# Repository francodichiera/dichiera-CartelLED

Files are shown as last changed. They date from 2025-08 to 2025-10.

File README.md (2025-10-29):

# Cartel LED inteligente Proyecto Final 2025
###
<p align="center">
  Imagen 1
</p>

<table align="center">
  <tr>
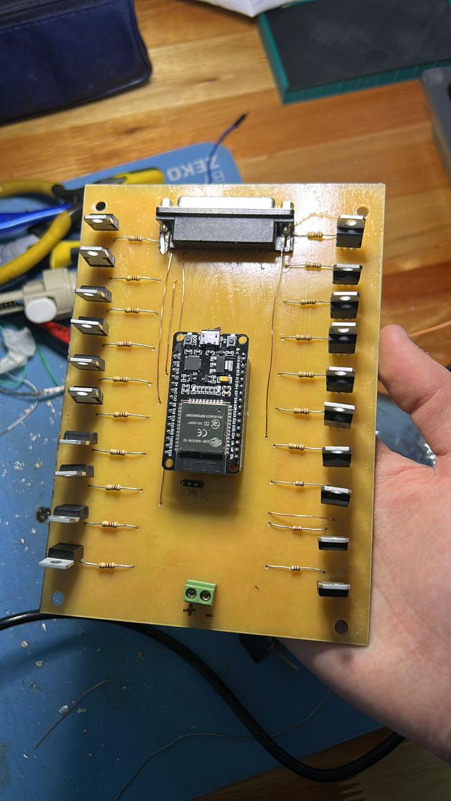
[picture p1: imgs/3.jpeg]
Imagen 3
    <td></td>
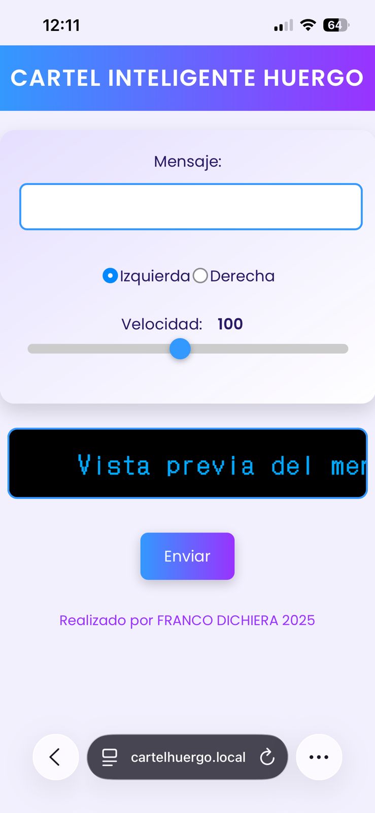
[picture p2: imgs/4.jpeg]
Imagen 4
    <td></td>
  </tr>
</table>

###
## 
- Proyecto: cartel LED multiplexado controlado por ESP32, columnas por 3×74HC595 (24 cols), filas por transistores TIP122.
(POR CADA MODULO).

- EL CARTEL CUENTA CON 18 FILAS x 96 COLUMNAS (4 MODULOS CONECTADOS HORIZONTALMENTE).

- CON UNAS DIMENSIONES DE LA ESTRUCTURA DE: 1.7m x 40cm.

## Agradecimientos

Antes de pasar a la explicacion, quiero agradecer especialmente al **Prof. Ing. Facundo Luzko** por su importante ayuda y guía en la programación del cartel, al **Prof. Ricardo Malvasio** por su valiosa orientación y colaboración durante el desarrollo del proyecto, y a **mi viejo**, por su apoyo incondicional en todo momento.

# Resumen

Este repositorio contiene el firmware para un cartel LED multiplexado con ESP32. Usa 3 registros 74HC595 en cascada para controlar 24 columnas y 18 pines del ESP32 (a través de transistores TIP122 o drivers) para seleccionar filas. El microcontrolador corre un servidor web simple que permite enviar el texto que se desplaza horizontalmente (scroll), elegir dirección y velocidad y persiste la configuración en flash con `Preferences`.

# Características

-   Matriz: `MATRIX_ROWS = 18`, `MATRIX_COLS = 24` (configurable).
    
-   Control de columnas por 3×`74HC595` en cascada.
    
-   Control de filas por pines del ESP32 (transistores TIP122 u otro driver).
    
-   Framebuffer en RAM: `framebuffer[MATRIX_ROWS][BYTES_PER_ROW]`.
    
-   Librería gráfica `Adafruit_GFX` + fuente compilada.
    
-   Interfaz web responsive para editar el mensaje, ver demo y ajustar velocidad/dirección.
    
-   Persistencia con `Preferences` (mensaje, velocidad, dirección).
    
-   mDNS disponible: `cartelhuergo.local` (si mDNS funciona en tu red).

----------

# Diagrama y conexionado (detalle)

> **Nota importante:** el ejemplo asume columnas manejadas por 74HC595 como _fuente_ (HIGH = +V para anodos) y filas controladas por NPN (TIP122) que _conectan a GND_ (sink) cuando activadas. Esta es la configuración que coincide con el comportamiento del código (`sr.set(b, HIGH)` y `digitalWrite(filas[f], HIGH)` para activar fila).

### Conexiones básicas

Señales principales (ESP32 ↔ 74HC595)

- DATA_PIN (23) -> Serial Data (DS / SER) del primer 74HC595

- CLOCK_PIN (18) -> Shift clock (SH_CP)

- LATCH_PIN (19) -> Store clock / latch (ST_CP)

### Salidas 74HC595 -> columnas

-   Q0..Q7 (primer registro) -> columnas 0..7
    
-   Q0..Q7 (segundo registro) -> columnas 8..15
    
-   Q0..Q7 (tercer registro) -> columnas 16..23

Asegurate del orden físico: la librería / código usa `sr.set(b, value)` con `b` de 0 a 23. Si tus registros están conectados en distinto orden, reordena o ajusta mapping.

### Filas (por TIP122)

Cada fila física (catodo común en el esquema) va a un TIP122 que tiene:

-   Colector -> pin fila (panel LED)
    
-   Emisor -> GND
    
-   Base -> pin ESP32 a través de resistencia de 1k  
    En el código `digitalWrite(filas[f], HIGH)` activa la fila (enciende transistor, conecta a GND).

### Alimentación

-   **Fuente**: calcula la corriente por LED (Iled) × cantidad máxima encendida simultáneamente. En multiplexado de filas, una sola fila se enciende a la vez, por lo que la corriente máxima es (#LEDsPorFila × Iled). Ejemplo: 24 LEDs por fila × 20 mA = 480 mA por fila (añadir margen). Para 18 filas multiplexadas no sumes todas; la fuente debe poder suministrar el pico por fila y la electrónica.
    
-   **Voltage registers**: 74HC595 soporta Vcc 2–6V; si usas LED de 5V considera 5V lógica o usar nivel shifters. Con ESP32 (3.3V) se suele usar 5V para LEDs y la salida del 74HC595 a 5V está OK si los 74HC595 toleran 3.3V en entradas. Revisa datasheets o usa versiones 74HCT (más compatible con 3.3V).
    
-   GND común obligatorio.

----------

# Cómo funciona (conceptos clave)

1.  **Framebuffer**: `uint8_t framebuffer[MATRIX_ROWS][BYTES_PER_ROW];`
    
    -   Cada fila tiene `BYTES_PER_ROW` bytes (3) → 24 columnas → 24 bits por fila.
        
    -   El bit más significativo (0x80) corresponde a la columna `x % 8 == 0` por el cálculo `0x80 >> (x % 8)`.
        
2.  **Dibujo**: Heredas `Adafruit_GFX` con `MatrixDisplay` y sobreescribes `drawPixel(x,y,color)`. Cuando se escribe texto con `display.print(curMessage)` Adafruit_GFX setea pixels en el framebuffer.
    
3.  **Multiplexado**:
    
    -   `refrescarMatrizCompleta()` recorre filas `f = 0..MATRIX_ROWS-1`.
        
    -   Para cada fila: apaga fila previa, envía todos los 24 bits (columnas) al `74HC595` con `sr.set(b, ...)`, activa la fila actual (`prenderFila(f)`), espera `delayMicroseconds(100)` y la apaga.
        
    -   Los LEDs que deben estar on durante esa fila se encienden porque sus columnas están `HIGH` (desde el 74HC595) y la fila está siendo _sink_ por el TIP122.
        
4.  **Scroll**:
    
    -   `xPos` controla la posición horizontal; cada `scrollSpeed` ms el texto avanza `±1`.
        
    -   `display.getTextBounds()` calcula anchura `w` del texto para resetear `xPos`.
        
5.  **Web**:
    
    -   Un web server simple en puerto 80 sirve `WebPage` y procesa parámetros en URL `?MSG=...&SD=L|R&SP=xxx`.
        
    -   El código parsea URL en `getData()` decodificando `%xx`.
        
6.  **Persistencia**:
    
    -   `Preferences` guarda `mensaje`, `speed`, `dir` para restaurar tras reset.

----------

## Explicación técnica: ¿qué es y cómo funciona un TIP122?

**TIP122 — resumen práctico**

-   El TIP122 es un transistor Darlington NPN empaquetado (dos transistores en cascada dentro de un solo encapsulado).
    
-   Ventaja: **ganancia de corriente muy alta** (β muy grande), por eso con poca corriente de base podés conmutar corrientes relativamente altas en el colector.
    
-   Desventaja: **alta caída de saturación** (VCE(sat) típicamente ~1.5–2.5 V dependiendo de corriente), lo que produce **pérdida de potencia** y calor. Además la caída base-emisor de la entrada es mayor (~2.5–3V total, por las dos uniones).

**Cómo se usa en el cartel**

-   Usamos TIP122 como _sink_ por fila: cuando su base recibe HIGH, el transistor conecta la fila a GND permitiendo que los LEDs de esa fila con columna HIGH se iluminen.
    
-   Colocá **una resistencia en la base** entre ESP32 y la base del TIP122 (ej. 1kΩ es una buena práctica). Esto limita la corriente desde el pin del ESP32.

**Cálculos y precauciones**

-   Si `I_collector = 480 mA` y `VCEsat ≈ 2 V` → potencia en el transistor `P = VCEsat × I = 2 V × 0.48 A = 0.96 W`. Esto **genera calor** y normalmente requiere disipador.
    
-   Con ESP32 (GPIO a 3.3 V) la base del TIP122 queda con poca tensión sobre la resistencia (Vbase ≈ 2.5 V), por eso la corriente de base es pequeña — aun así la ganancia Darlington suele permitir conmutar la corriente del colector.
    
-   **Recomendación:** para menor pérdida térmica y menor VCE(sat) usar un **MOSFET N-channel lógico (logic-level)** como alternativa — mucho menor VDS(on) y menos calor. Ej: si conseguís un MOSFET de canal N con Rds(on) bajo y que se active con 3.3 V (IRLZ44N no siempre es la mejor opción, buscá específicamente “logic-level MOSFET”), vas a reducir pérdidas térmicas.

**Valores orientativos**

-   Resistencia base típica: `1kΩ` (puede ajustarse entre 470Ω y 4.7kΩ según diseño).
    
-   Verifica disipación térmica y agrega disipador o cambialo por MOSFET si vas a manejar corrientes grandes.

----------

## Explicación técnica: ¿qué es y cómo funciona un 74HC595?

**74HC595 — resumen práctico**

-   Es un _registro de desplazamiento (shift register)_ con latch y 8 salidas paralelas (Q0..Q7).
    
-   Funcionalmente tiene dos registros internos:
    
    -   **Shift register**: donde se van desplazando los bits con cada pulso de reloj (SH_CP).
        
    -   **Storage register** (o latch register): se actualiza cuando se pulsea ST_CP (latch). De este modo podés enviar muchos bits sin que las salidas cambien hasta que hagas latch.
        
-   Señales principales:
    
    -   `SER` (DS): serial data in
        
    -   `SH_CP` (clock): desplaza un bit en el shift register al flanco activo
        
    -   `ST_CP` (latch): copia el contenido del shift register al storage register → las salidas cambian
        
    -   `Q0..Q7`: salidas paralelas
        
    -   `Q7'` (o Q7S/Q7') suele ser serial out para encadenar el siguiente 74HC595 (cascada)
        
    -   `OE` (Output Enable, activa low) y `MR` (Master Reset, activa low) controlan si las salidas están habilitadas o si el registro se resetea

**Por qué lo usamos**

-   Permite controlar **muchas columnas** con solo 3 pines del micro (data, clock, latch).
    
-   Con `Q7'` encadenás los registros y podés manejar 24 columnas en serie.

**Consejos de uso**

-   **Cargar todos los bits** (ej. 3 bytes) en el shift register con pulsos de clock y al final hacer un `latch` para actualizar las salidas en una operación atómica. Esto evita glitches.
    
-   `OE` lo podés usar para blanking rápido (si querés apagar todas las salidas momentáneamente).
    
-   `MR` te permite resetear las salidas (activo bajo).

**Limitaciones eléctricas importantes**

-   Los pines del 74HC595 no están pensados para conducir corrientes muy altas de forma sostenida. Aunque pueden entregar decenas de mA en condiciones cortas, **no es buena idea esperar 20–25 mA sostenidos por salida sin verificar la hoja de datos**.
    
-   En multiplexado, cada salida del 74HC595 típicamente solo alimenta un LED a la vez (por fila), lo que reduce la corriente sostenida por pin, pero **es crucial usar resistencias por LED** y mantener la corriente por pin dentro de límites razonables.
    
-   Para compatibilidad con **ESP32 (3.3 V)** se recomienda la versión **74HCT595** o comprobar que la lógica 74HC595 que uses interpreta 3.3 V como HIGH de forma fiable. `74HCT` suele aceptar 3.3 V como HIGH cuando la alimentación del chip es 5 V — aún así, revisar datasheets.

**Buenas prácticas**

-   Si necesitás más corriente o brillo, usar drivers especializados para LEDs (p. ej. registros con driver de corriente constante) o agregar transistores por columna si vas a exigir >10 mA por salida.
    
-   Si microcontrolador y 74HC595 comparten diferentes tensiones (3.3V vs 5V), considera conversión de niveles o usar 74HCT compatibles.

# Dependencias y preparación del entorno

-   **Placa:** ESP32 (seleccionar en Arduino IDE -> Board Manager).
    
-   **Librerías (instalar desde Library Manager / Git):**
    
    -   `ShiftRegister74HC595` (o la que uses; tu código ya referencia la plantilla `ShiftRegister74HC595<3>`).
        
    -   `Adafruit_GFX` (para la API gráfica).
        
    -   `ESPmDNS` (incluida con núcleo ESP32).
        
    -   `Preferences` (incluida).
        
    -   Fuente convertida a header: `LEMONMILK_Regular11pt7b` (como `Fonts/LEMONMILK_Regular11pt7b.h`). Para convertir TTF → Adafruit font: usar `truetype2gfx` o `fontconvert` (links en comentarios del código).
        
        > `https://rop.nl/truetype2gfx/ FONTS PAGE`

### Recomendaciones de configuración en Arduino IDE

-   Board: `ESP32 Dev Module` (o el modelo exacto)
    
-   Flash Frequency: 80 MHz
    
-   Upload Speed: 115200 o 921600 (según tu puerto)
    
-   Partition Scheme: default (si necesitas mucha NVS, ajustar)

----------

# Interfaz Web / API

-   Página principal (sirve `WebPage`) incluye demo y formulario.
    
-   **Enviar**: pulsa `Enviar` en la UI → hace `window.location='/?MSG='+msg+'&SD='+SD+'&SP='+SP`.
    
-   **Formato URL manual**:
    
    `http://<IP_DEL_ESP32>/?MSG=Tu%20mensaje%20aqui&SD=L&SP=100` 
    
    -   `MSG` = texto codificado en URL (máx 255 chars en tu buffer).
        
    -   `SD` = `L` (izquierda) o `R` (derecha).
        
    -   `SP` = velocidad (entero). En tu código `scrollSpeed` en ms.
        
-   **Demo**: la demo en el HTML hace scroll CSS/JS y usa fuente tipo LED (DotGothic16).

----------

# Configuraciones persistentes

-   Namespace `prefs.begin("cartel", false);`
    
-   Keys:
    
    -   `"mensaje"` (String)
        
    -   `"speed"` (uint)
        
    -   `"dir"` (bool)
        
-   Para resetear preferencias manualmente: puedes añadir un endpoint `/reset` que haga `prefs.clear()` o borrar desde código.

----------

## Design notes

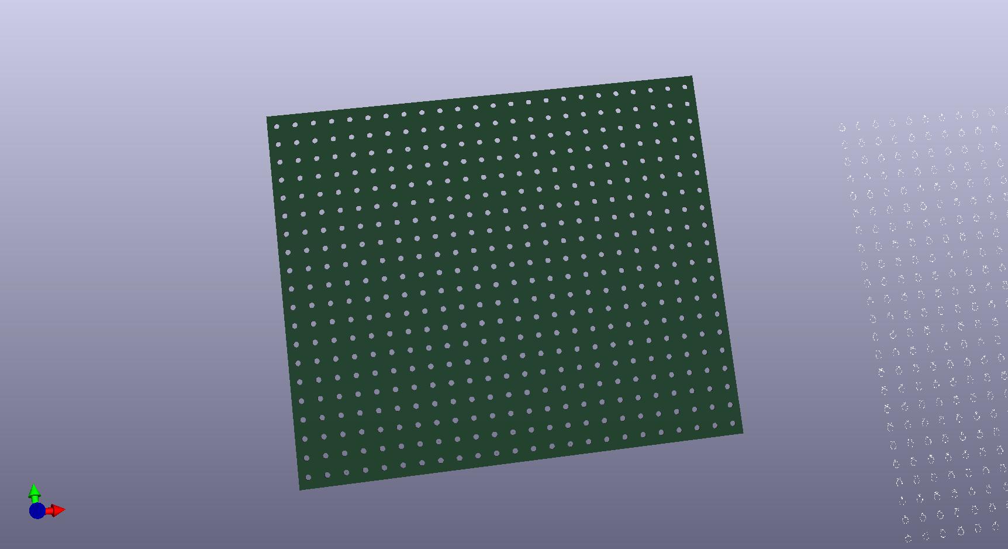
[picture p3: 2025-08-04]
assets/Matriz Franco 20x24/cartelmatriz.jpg

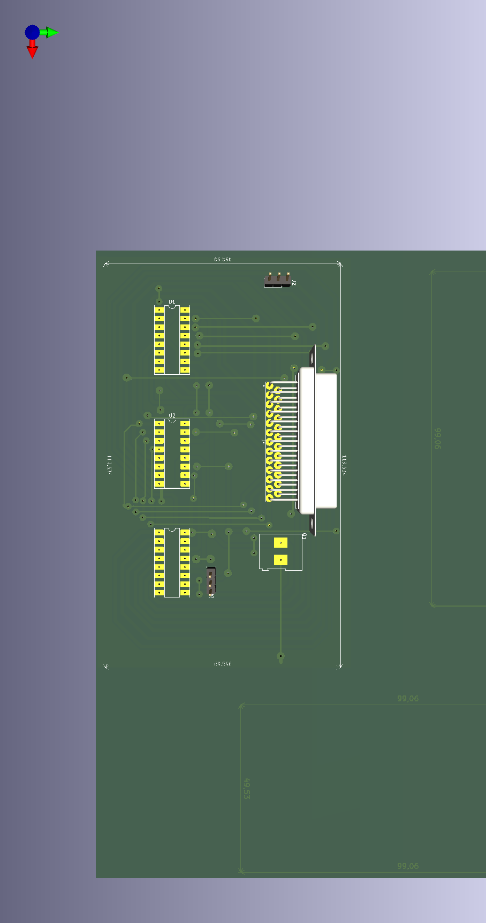
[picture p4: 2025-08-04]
assets/Placa 74hc595 Version 2/74hc595/74hc595.png

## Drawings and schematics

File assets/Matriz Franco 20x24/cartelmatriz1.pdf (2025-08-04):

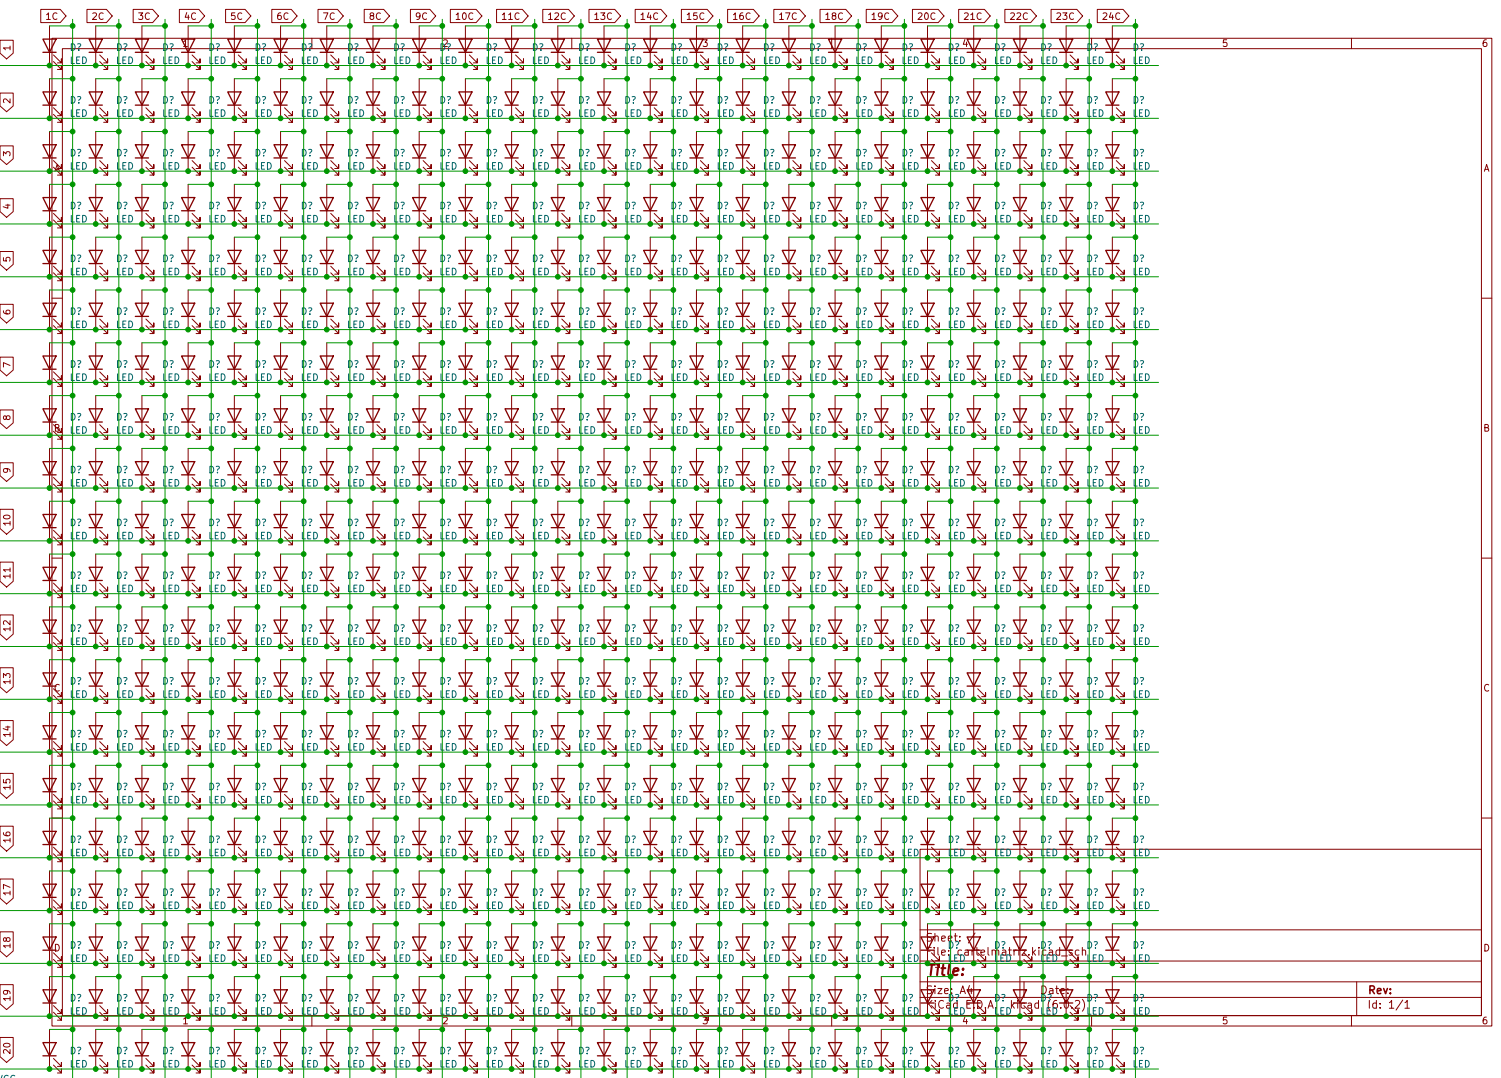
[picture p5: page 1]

D? | D? | D? | D?
LED | LED | LED | LED | LED

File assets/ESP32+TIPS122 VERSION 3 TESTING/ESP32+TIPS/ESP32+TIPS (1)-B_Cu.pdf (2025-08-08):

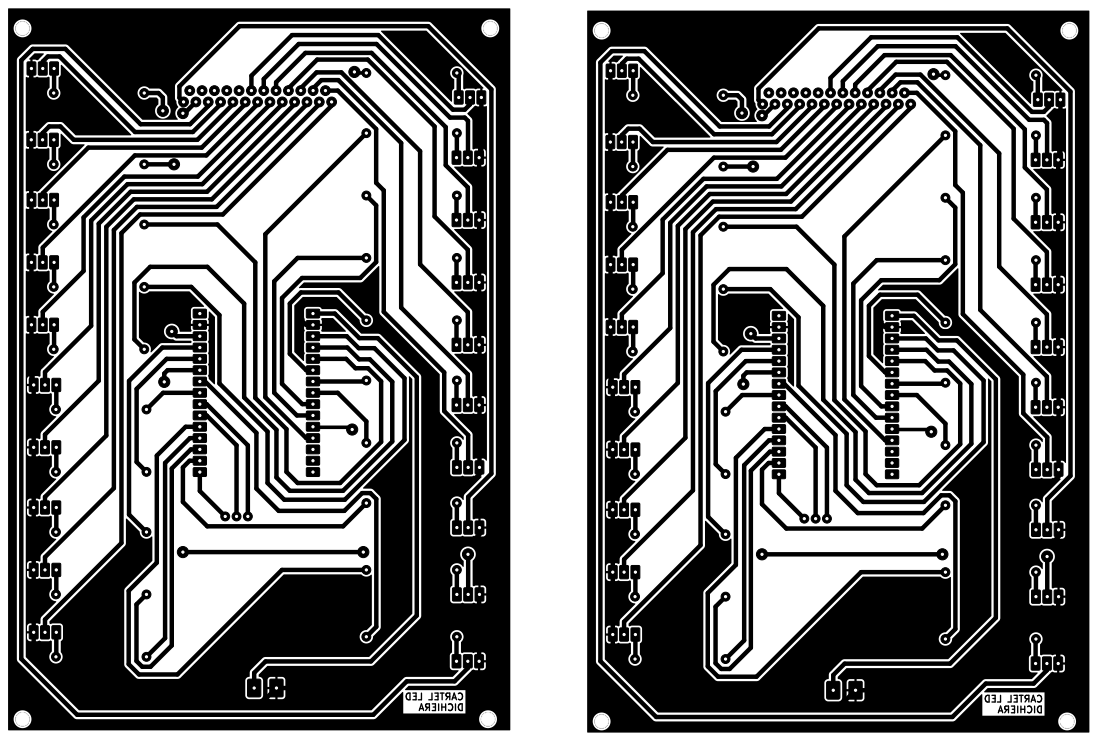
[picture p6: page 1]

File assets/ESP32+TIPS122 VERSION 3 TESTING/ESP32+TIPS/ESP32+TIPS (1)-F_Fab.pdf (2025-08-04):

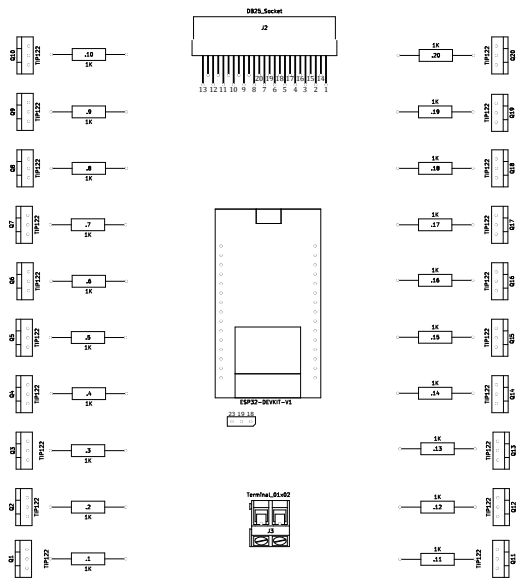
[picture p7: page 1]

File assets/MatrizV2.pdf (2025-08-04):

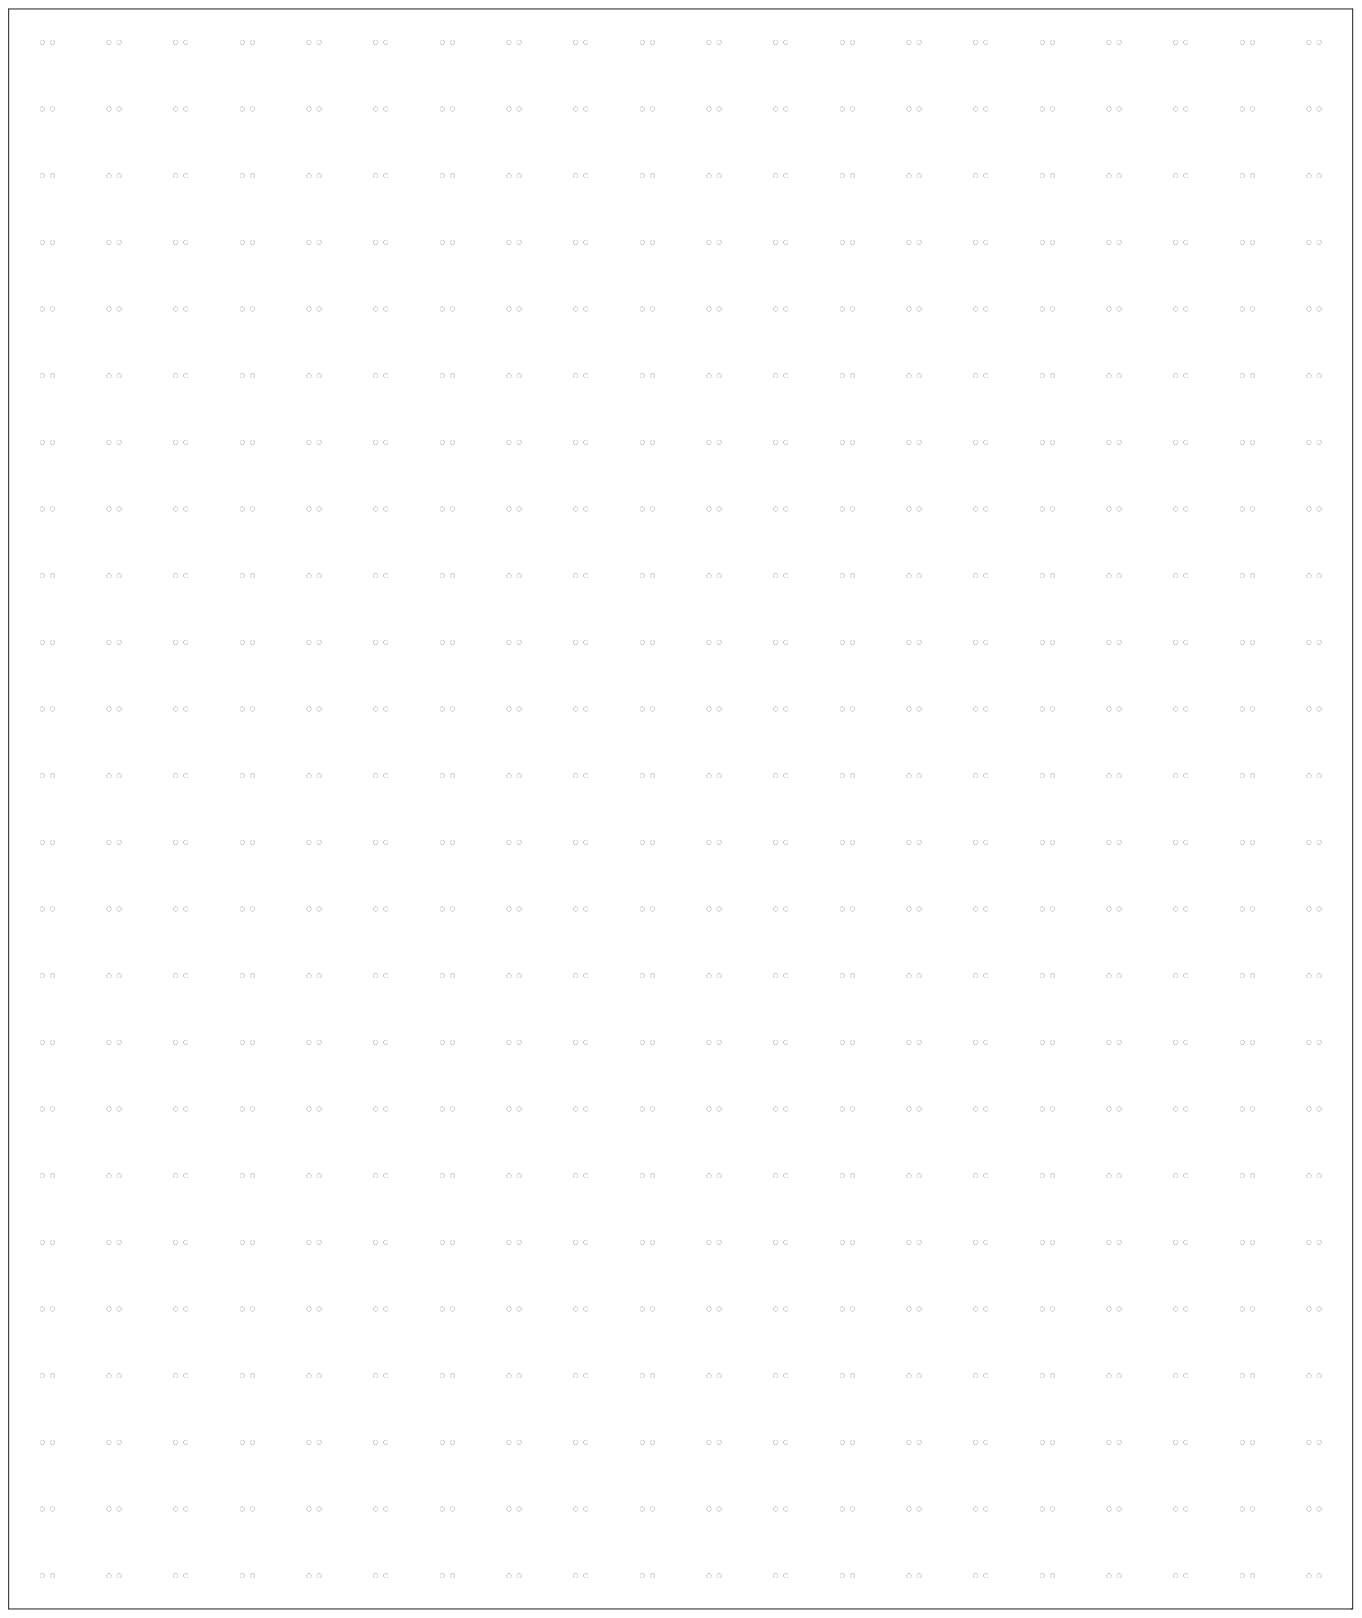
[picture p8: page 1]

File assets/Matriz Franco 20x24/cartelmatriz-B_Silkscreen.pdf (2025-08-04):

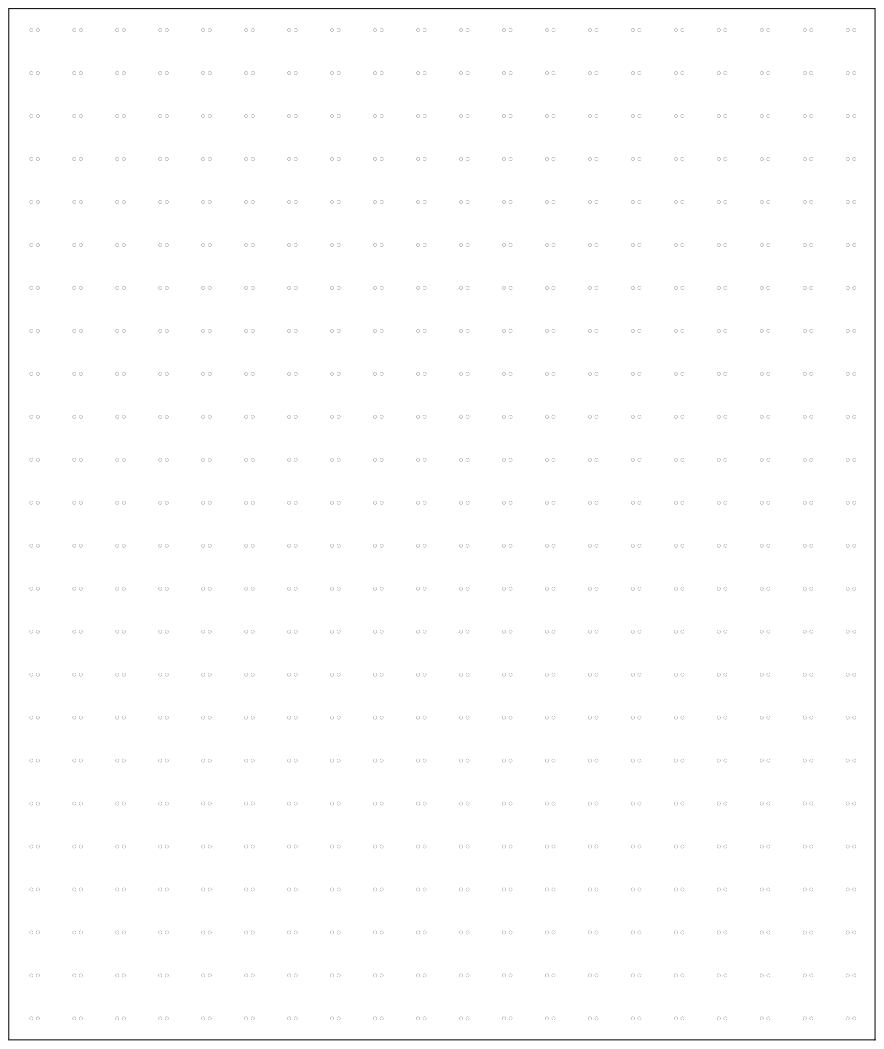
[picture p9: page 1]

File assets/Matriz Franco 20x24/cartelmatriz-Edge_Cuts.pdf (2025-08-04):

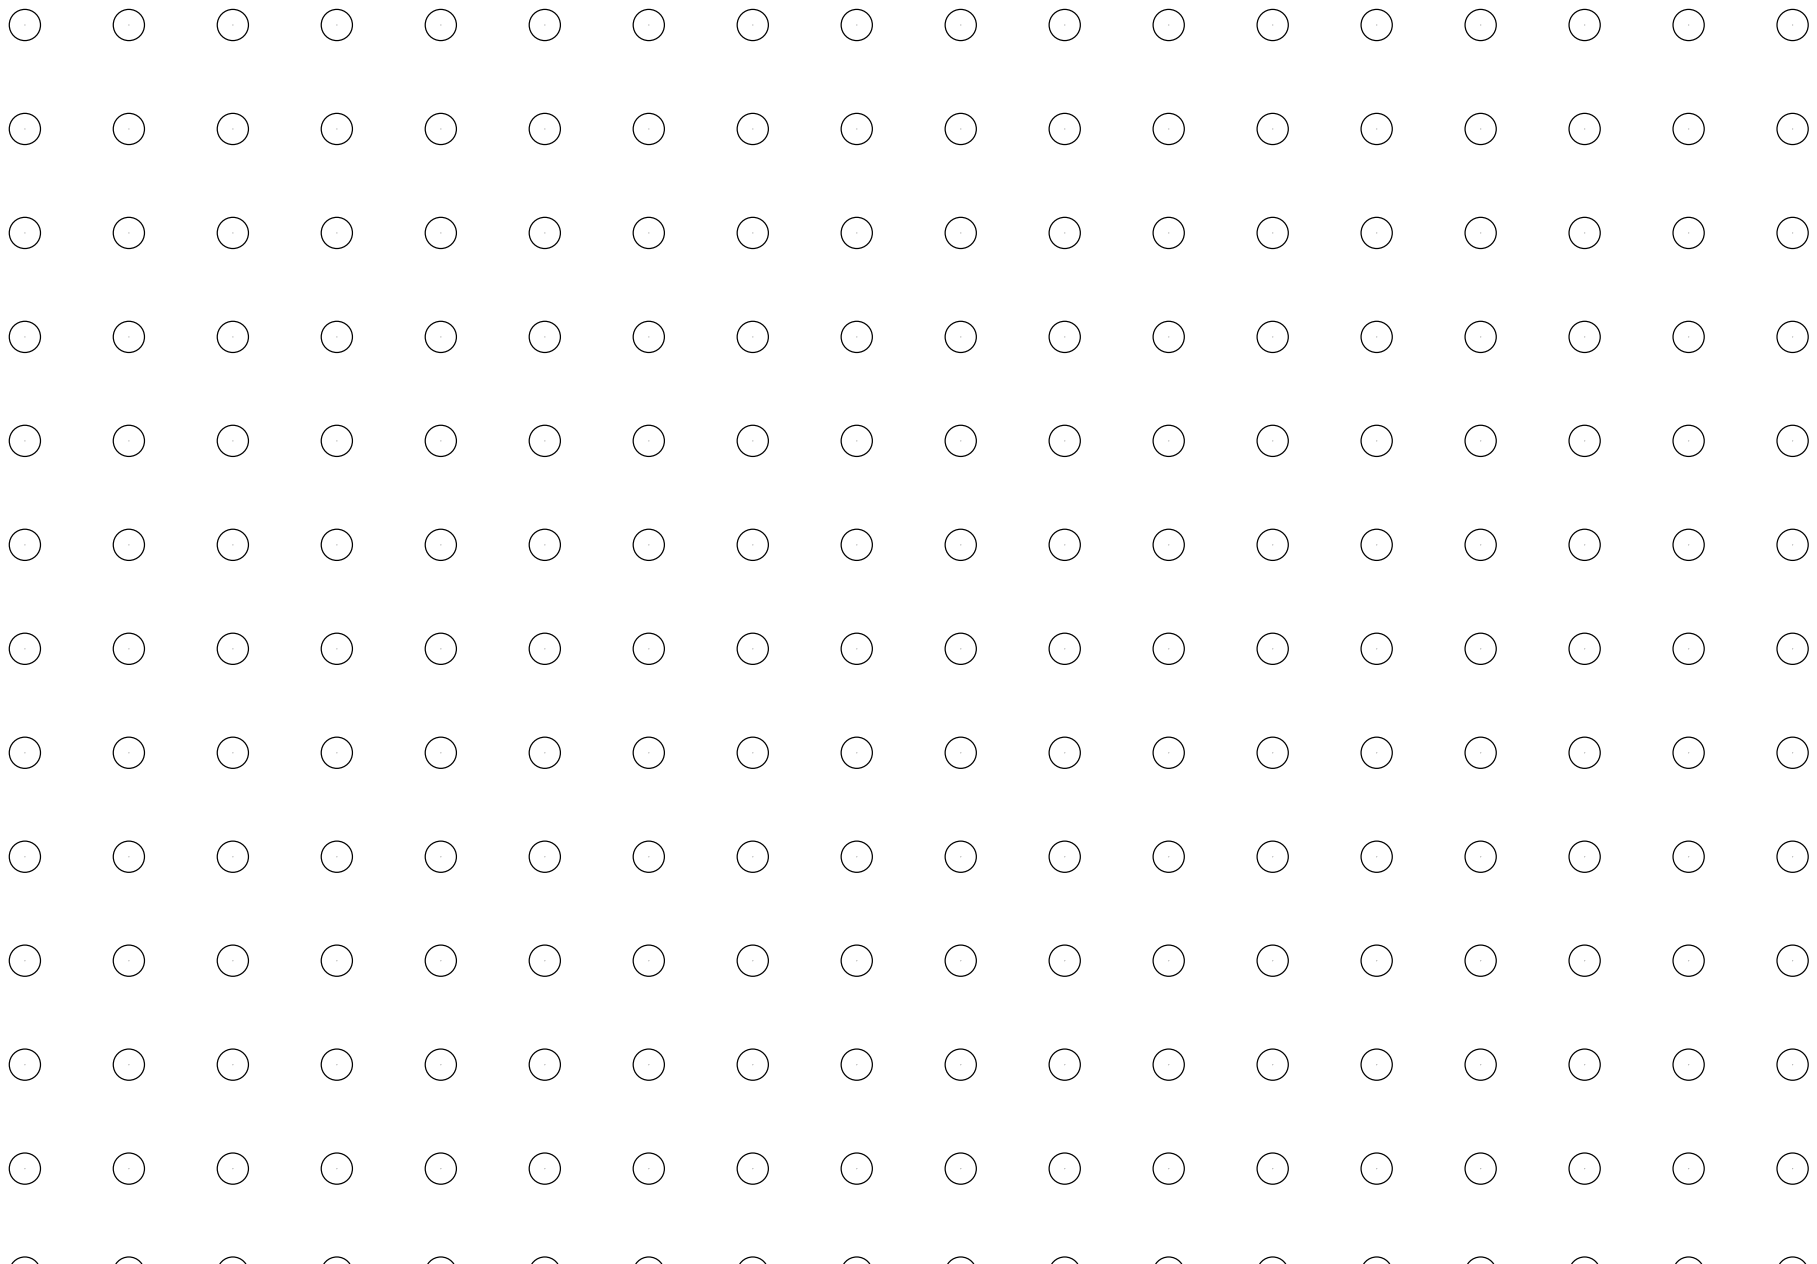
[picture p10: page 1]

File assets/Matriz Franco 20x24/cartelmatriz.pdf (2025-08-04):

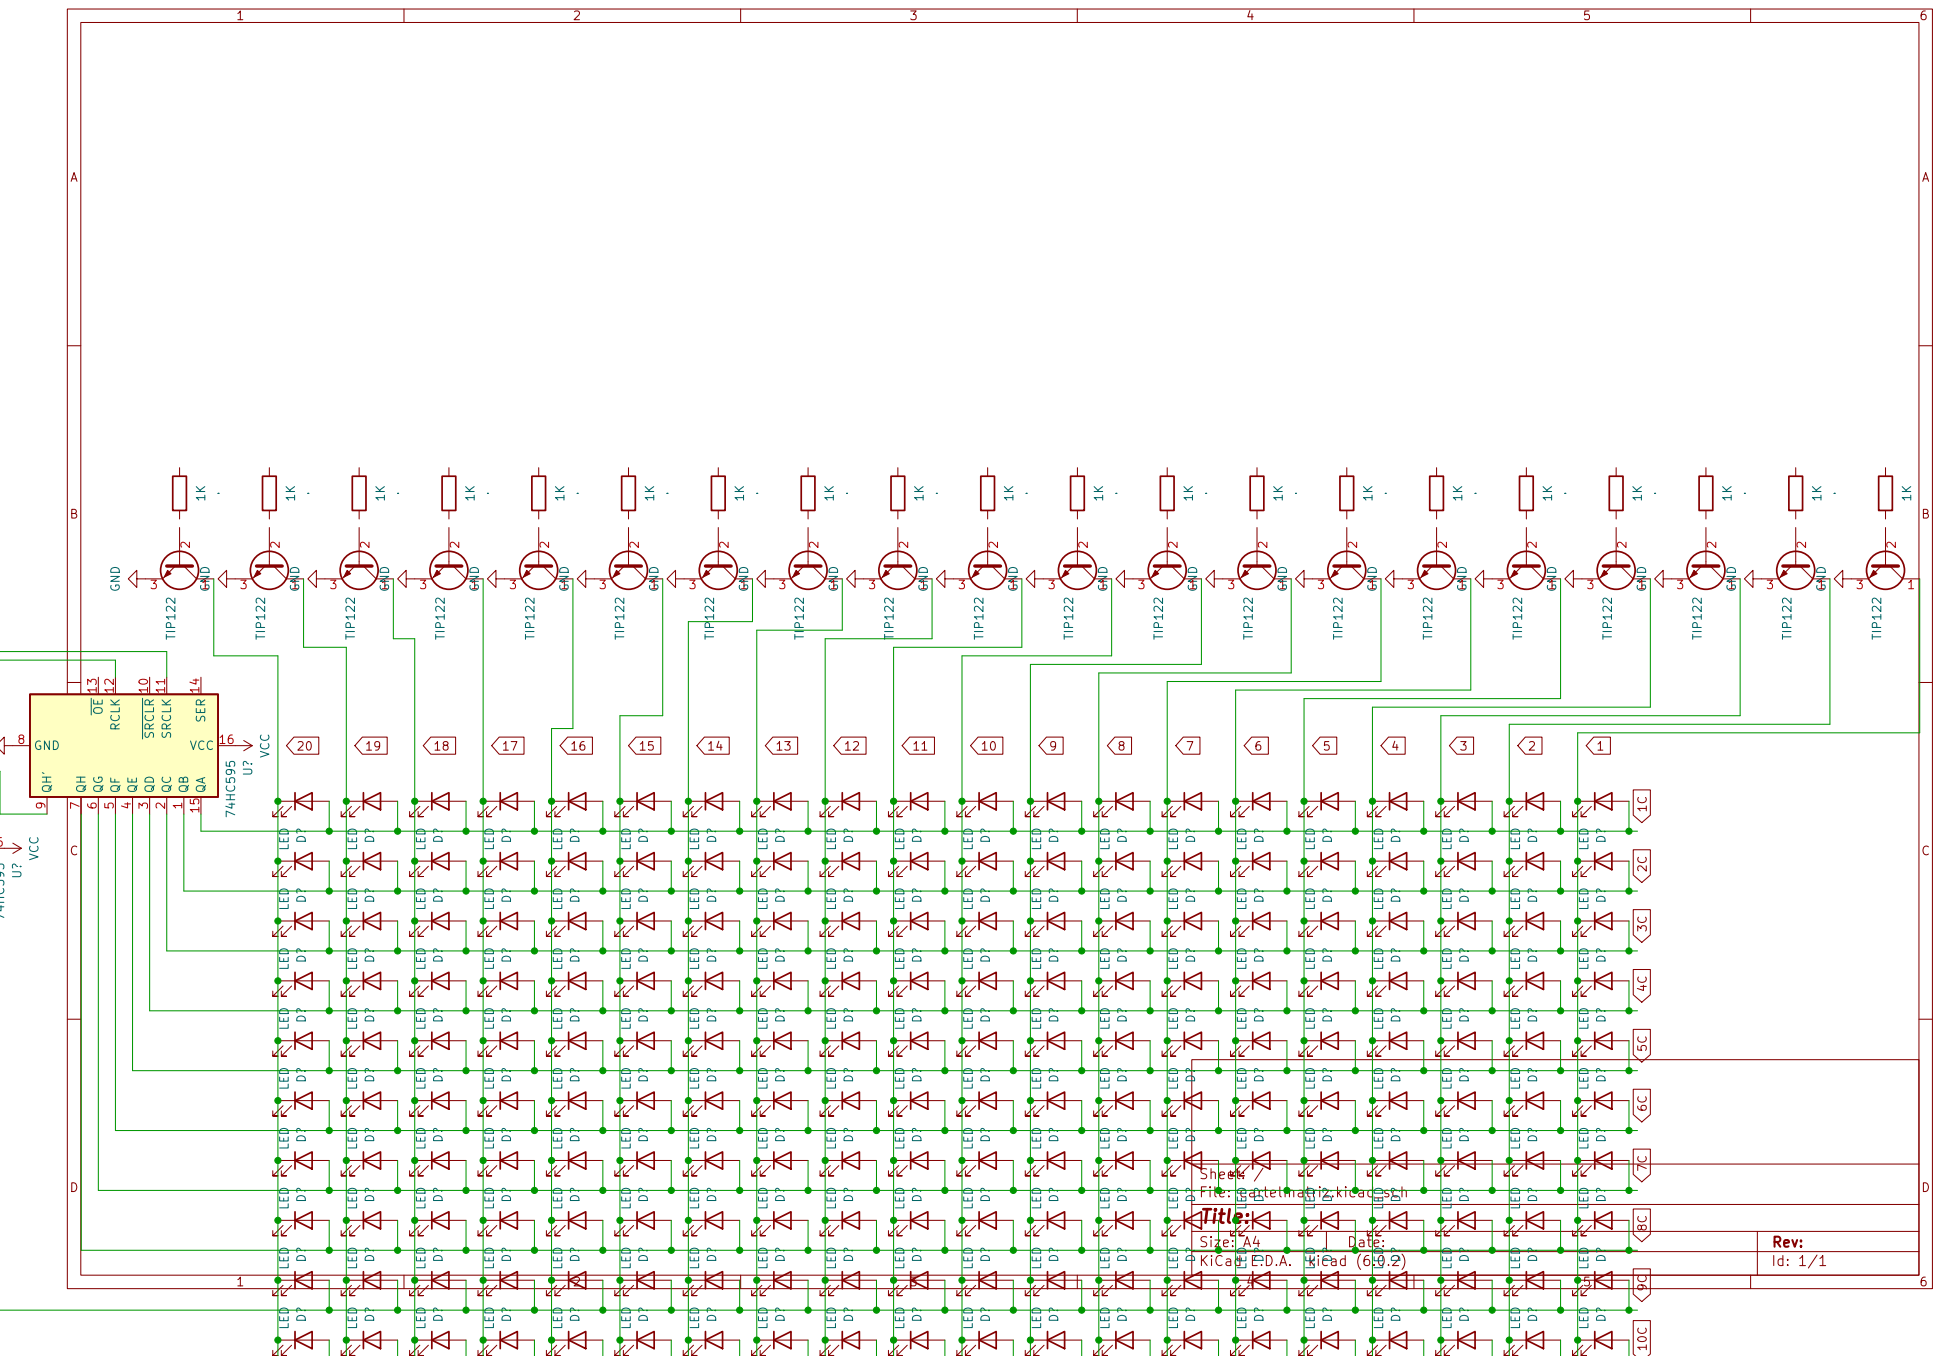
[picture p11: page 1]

1 ~{SRCLR}10 SRCLK 11 RCLK 12 ~{OE}13 SER 14 QA 15 VCC 16 QC

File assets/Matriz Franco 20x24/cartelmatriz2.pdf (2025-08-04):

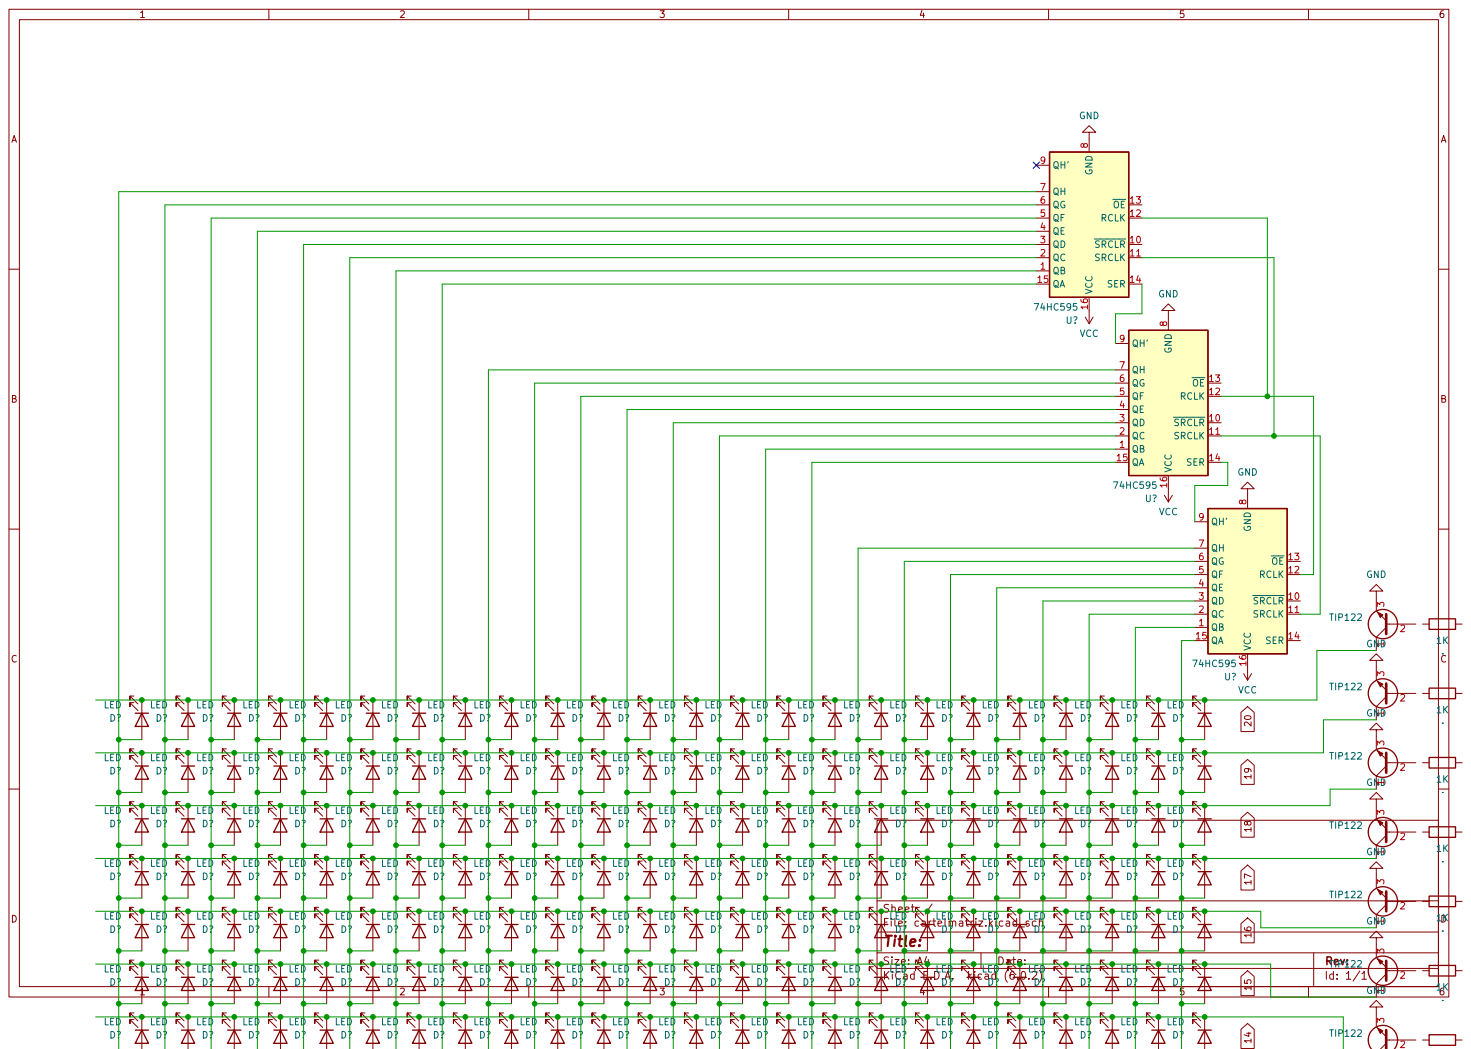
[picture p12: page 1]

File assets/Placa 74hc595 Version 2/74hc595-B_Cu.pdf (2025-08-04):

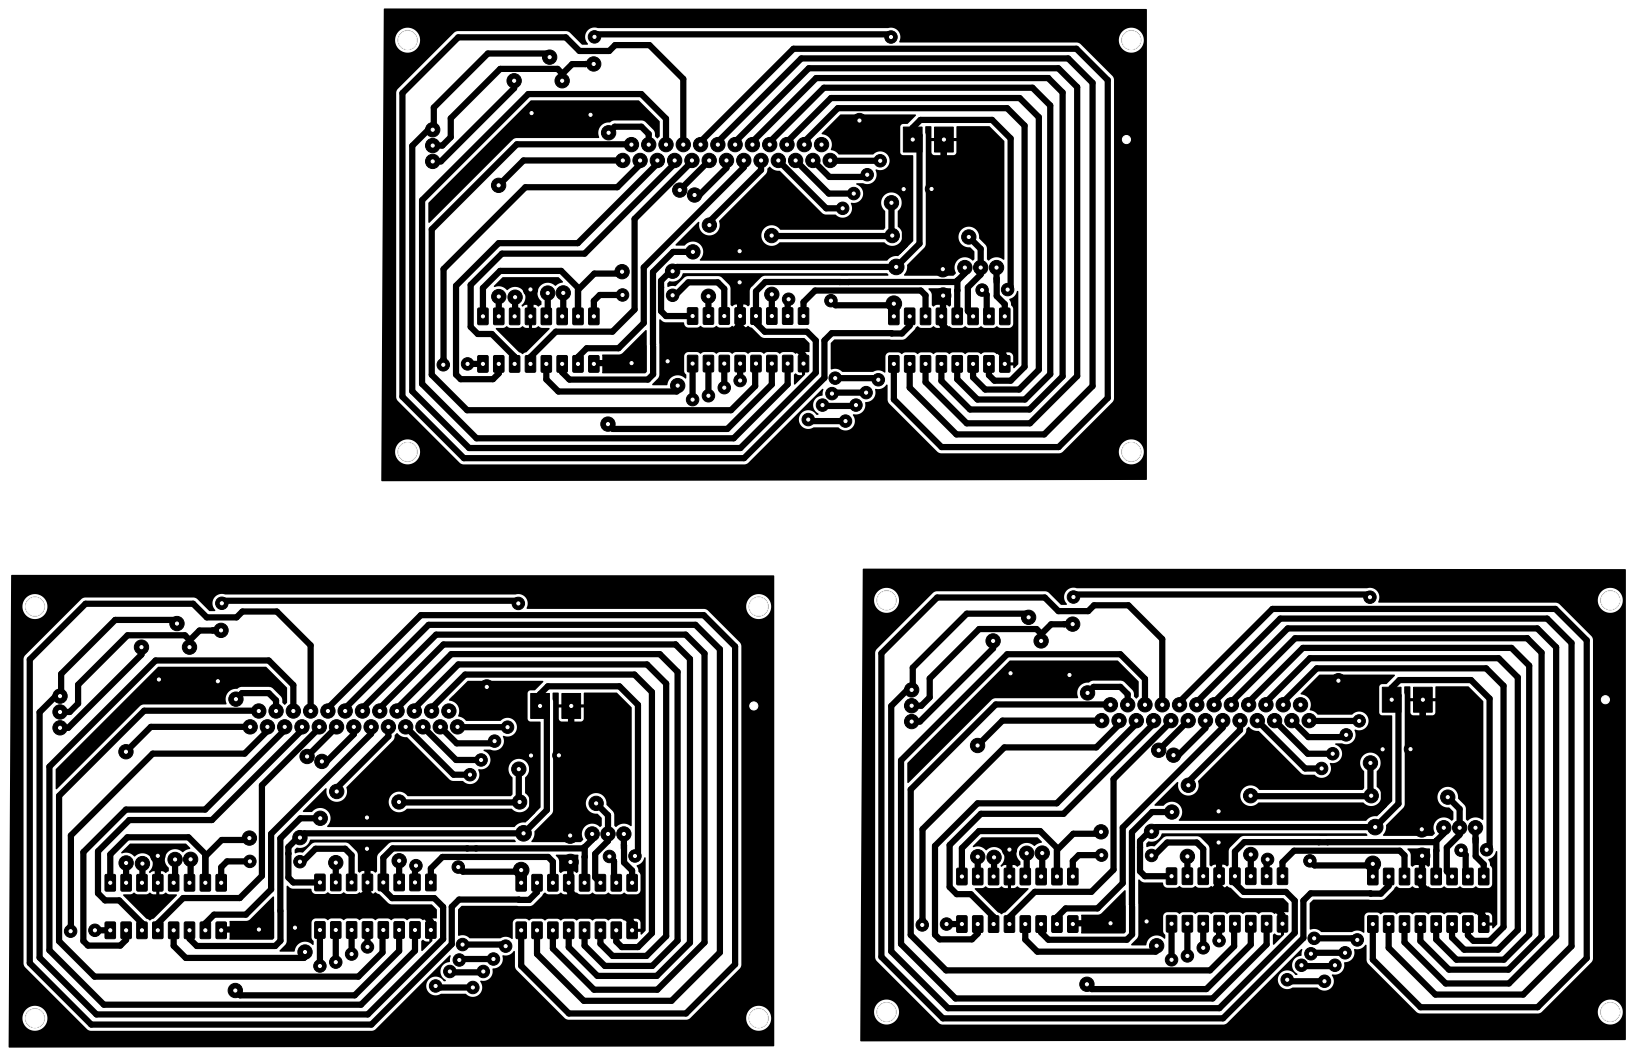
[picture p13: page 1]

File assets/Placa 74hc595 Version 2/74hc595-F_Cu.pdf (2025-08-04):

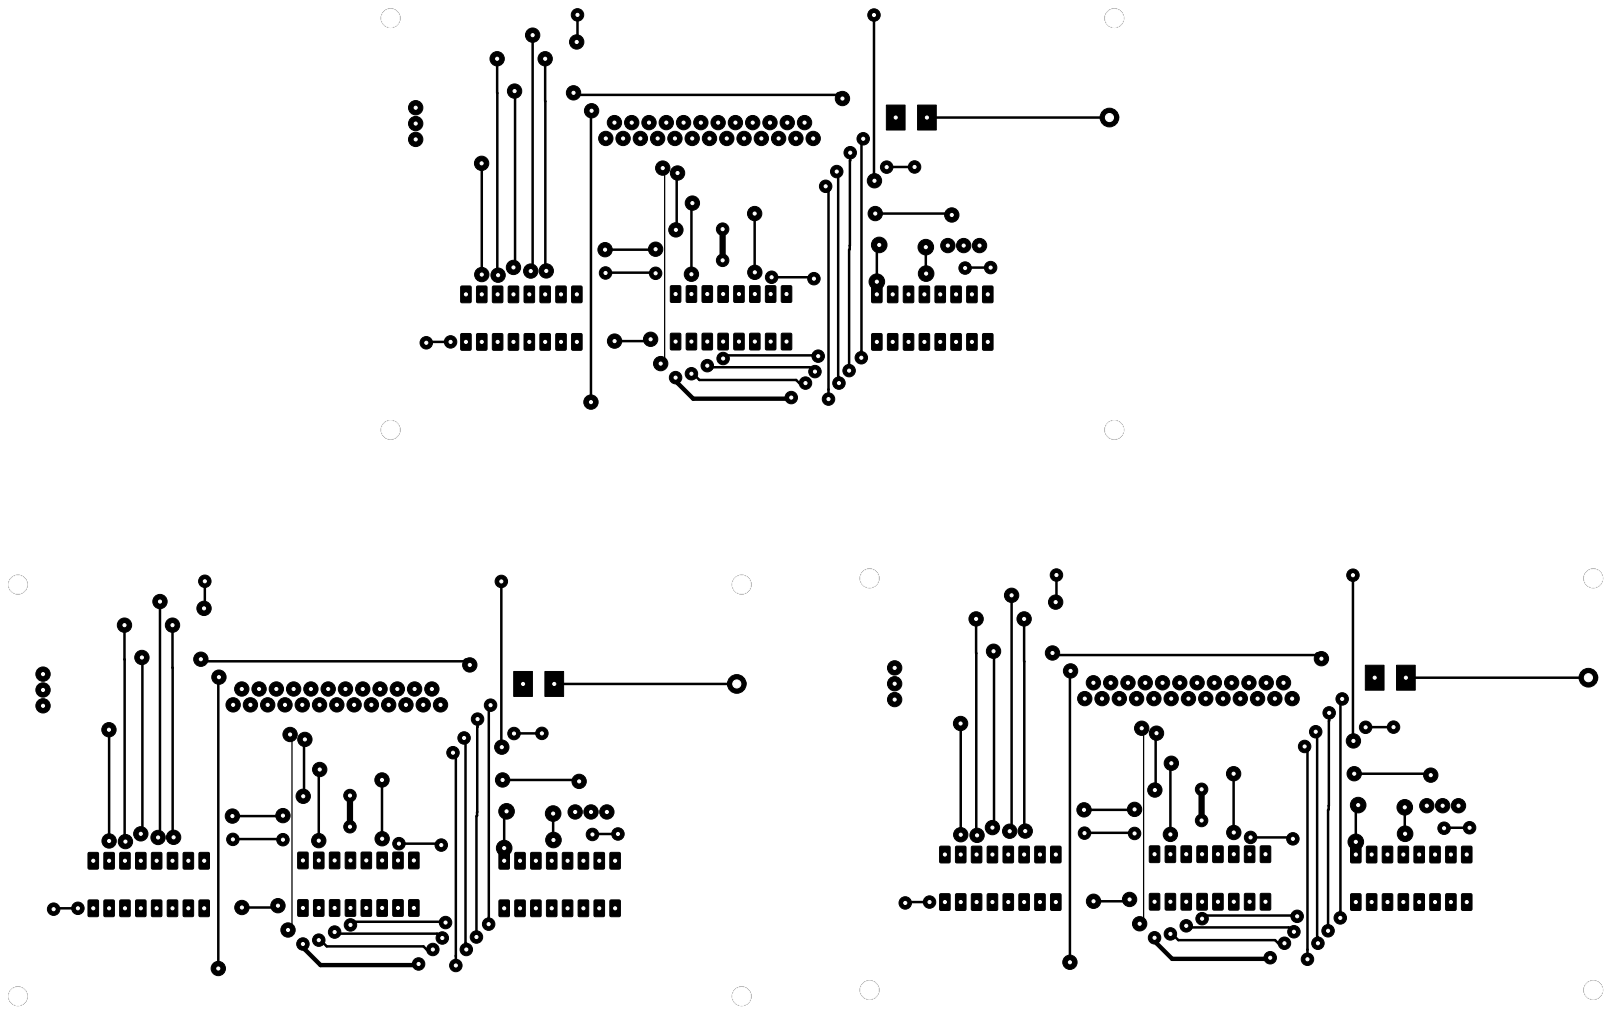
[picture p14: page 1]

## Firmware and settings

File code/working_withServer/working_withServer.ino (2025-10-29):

#include <Arduino.h>
#include <WiFi.h>
#include <ESPmDNS.h>
#include <ShiftRegister74HC595.h>
#include <Adafruit_GFX.h>
#include <Fonts/LEMONMILK_Regular10pt7b.h>  //https://rop.nl/truetype2gfx/ FONTS PAGE
#include <Preferences.h>

// === CREDENCIALES WiFi ===
const char *ssid = "CARTEL-LED";    // Nombre de la red WiFi
const char *password = "12345678";  // Contraseña de la red WiFi

// === PINES DE LA MATRIZ ===
#define DATA_PIN 23                      // Pin de datos para 74HC595
#define CLOCK_PIN 18                     // Pin de clock para 74HC595
#define LATCH_PIN 19                     // Pin de latch para 74HC595
#define MATRIX_ROWS 18                   // Cantidad de filas de la matriz de LEDs
#define MATRIX_COLS 96                   // Cantidad de columnas de la matriz de LEDs
#define BYTES_PER_ROW (MATRIX_COLS / 8)  // Cantidad de bytes por fila (24/8=3)

// === CONTROL DE REGISTROS 74HC595 ===
ShiftRegister74HC595<12> sr(DATA_PIN, CLOCK_PIN, LATCH_PIN);  // 3 registros en cascada para 24 columnas

const uint8_t filas[MATRIX_ROWS] = { 3, 1, 2, 4, 5, 12, 13, 14, 15, 16, 17, 21, 22, 25, 26, 27, 32, 33 };  // Pines del ESP32 conectados a las filas (a través de TIP122 o transistores)

uint8_t framebuffer[MATRIX_ROWS][BYTES_PER_ROW];  // Framebuffer donde se almacena qué LEDs deben estar encendidos

// === CLASE PARA EL DISPLAY ===
class MatrixDisplay : public Adafruit_GFX {
public:
  MatrixDisplay()
    : Adafruit_GFX(MATRIX_COLS, MATRIX_ROWS) {}

  // Dibuja un píxel en el framebuffer
  void drawPixel(int16_t x, int16_t y, uint16_t color) override {
    if (x < 0 || x >= MATRIX_COLS || y < 0 || y >= MATRIX_ROWS) return;
    uint8_t bitMask = 0x80 >> (x % 8);      // Máscara para elegir el bit correcto
    uint8_t &byte = framebuffer[y][x / 8];  // Referencia al byte donde está ese LED
    if (color) byte |= bitMask;             // Si color != 0 → prende el LED
    else byte &= ~bitMask;                  // Si color == 0 → apaga el LED
  }

  // Limpia toda la pantalla
  void clear() {
    for (int i = 0; i < MATRIX_ROWS; i++)
      for (int j = 0; j < BYTES_PER_ROW; j++) framebuffer[i][j] = 0;
  }
};
MatrixDisplay display;  // Instancia global del display

// === FUNCIONES PARA CONTROLAR FILAS ===
void prenderFila(uint8_t f) {
  digitalWrite(filas[f], HIGH);  // Activa la fila f
}
void apagarFila(uint8_t f) {
  digitalWrite(filas[f], LOW);  // Desactiva la fila f
}

void refrescarMatrizCompleta() {
  for (uint8_t f = 0; f < MATRIX_ROWS; f++) {
    // Apagar todas las filas
    for (uint8_t i = 0; i < MATRIX_ROWS; i++) apagarFila(i);

    // Mandar datos de la fila
    for (uint8_t b = 0; b < BYTES_PER_ROW; b++) {
      uint8_t data = framebuffer[f][b];
      for (uint8_t bit = 0; bit < 8; bit++) {
        sr.setNoUpdate(b * 8 + bit, (data & (0x80 >> bit)) ? HIGH : LOW);
      }
    }
    sr.updateRegisters();

    // Encender la fila actual
    prenderFila(f);
    delayMicroseconds(100);  // probá 50–100 µs
    apagarFila(f);
  }
}

// === SERVIDOR HTTP ===
WiFiServer server(80);  // Servidor web en el puerto 80

#define BUF_SIZE 4096
char curMessage[BUF_SIZE] = "";    // Mensaje actual que se muestra
char newMessage[BUF_SIZE] = "";    // Nuevo mensaje recibido
bool newMessageAvailable = false;  // Flag para indicar si hay un nuevo mensaje
bool scrollRight = false;          // Dirección de scroll (false = izquierda, true = derecha)
uint16_t scrollSpeed = 100;        // Velocidad del scroll

// Preferences: guarda datos en memoria flash para que persistan tras reinicio
Preferences prefs;

// === PÁGINA WEB QUE MANEJA EL CARTEL ===
const char WebResponse[] = "HTTP/1.1 200 OK\nContent-Type: text/html\n\n";
const char WebPage[] =
  "<!DOCTYPE html><html><head><meta charset='UTF-8'><meta name='viewport' content='width=device-width,initial-scale=1.0,maximum-scale=1.0,user-scalable=no'><title>CARTEL INTELIGENTE HUERGO</title><style>body{font-family:Verdana,sans-serif!important;background:#f3f0ff;color:#2a1a66;text-align:center;margin:0;padding:0;}h1{background:linear-gradient(90deg,#3399ff,#9933ff);color:#fff;padding:15px 0;margin:0;font-size:1.5em;letter-spacing:1px;}form{padding:20px;background:linear-gradient(145deg,#e6e0ff,#fff);margin:20px auto;width:90%;max-width:420px;border-radius:15px;box-shadow:0 8px 20px rgba(0,0,0,0.15);text-align:center;transition:.3s;}form:hover{box-shadow:0 10px 25px rgba(0,0,0,0.25);}input[type=text]{width:95%;font-size:16px;padding:10px;margin:10px 0;border:2px solid #3399ff;border-radius:8px;transition:.3s;outline:none;font-family:sans-serif;}input[type=text]:focus{border-color:#9933ff;box-shadow:0 0 8px rgba(153,51,255,0.4);}input[type=range]{-webkit-appearance:none;width:95%;height:10px;border-radius:5px;background:#ccc;outline:none;}input[type=range]::-webkit-slider-thumb{-webkit-appearance:none;width:22px;height:22px;border-radius:50%;background:#3399ff;cursor:pointer;box-shadow:0 2px 6px rgba(0,0,0,0.3);transition:.3s;}input[type=range]::-webkit-slider-thumb:hover{background:#9933ff;}button{padding:12px 25px;margin-top:10px;background:linear-gradient(90deg,#3399ff,#9933ff);color:#fff;border:none;border-radius:8px;cursor:pointer;box-shadow:0 4px 12px rgba(0,0,0,0.2);transition:.3s;font-size:1em;font-family:sans-serif;}button:hover{background:linear-gradient(90deg,#0055aa,#6600cc);box-shadow:0 6px 15px rgba(0,0,0,0.3);}#speedVal{font-weight:bold;color:#2a1a66;display:inline-block;width:50px;text-align:center;font-family:sans-serif;}.demoScroll{margin:25px auto;padding:10px;width:90%;max-width:420px;background:#000;border:2px solid #3399ff;border-radius:10px;overflow:hidden;height:50px;display:flex;align-items:center;position:relative;}.ledText{color:#00aaff;font-family:Verdana,monospace;font-size:1.2em;font-weight:bold;letter-spacing:2px;text-shadow:none;white-space:nowrap;position:absolute;will-change:transform;}footer{margin-top:30px;color:#9933ff;font-size:.9em;font-family:sans-serif;}@media(max-width:500px){input[type=text],input[type=range]{width:95%;}}</style><script>let animId=null;function SendData(){var msg=encodeURIComponent(document.frm.Message.value);var SD=document.frm.ScrollType.value;var SP=document.frm.Speed.value;window.location='/?MSG='+msg+'&SD='+SD+'&SP='+SP;}function updateSpeed(val){document.getElementById('speedVal').innerText=val;updateDemo();}function updateDemo(){const txt=document.frm.Message.value||'Vista previa del mensaje';const dir=document.frm.ScrollType.value;const spd=document.frm.Speed.value;const el=document.getElementById('demoText');el.textContent=txt;if(animId)cancelAnimationFrame(animId);const parent=el.parentNode;let pos=(dir==='L')?parent.offsetWidth:-el.offsetWidth;function step(){let velocidad=spd/20;pos+=(dir==='L'?-1:1)*velocidad;if((dir==='L'&&pos<-el.offsetWidth)||(dir==='R'&&pos>parent.offsetWidth)){pos=(dir==='L')?parent.offsetWidth:-el.offsetWidth;}el.style.transform='translateX('+pos+'px)';animId=requestAnimationFrame(step);}step();}window.onload=updateDemo;</script></head><body><h1>CARTEL INTELIGENTE HUERGO</h1><form name='frm'>Mensaje:<br><input type='text' name='Message' maxlength='255' oninput='updateDemo()'><br><br><input type='radio' name='ScrollType' value='L' checked onclick='updateDemo()'>Izquierda <input type='radio' name='ScrollType' value='R' onclick='updateDemo()'>Derecha<br><br>Velocidad: <span id='speedVal'>100</span><br><input type='range' name='Speed' min='10' max='200' value='100' oninput='updateSpeed(this.value)'><br><br></form><div class='demoScroll'><div id='demoText' class='ledText'>Vista previa del mensaje</div></div><button onclick='SendData()'>Enviar</button><footer>Realizado por FRANCO DICHIERA 2025</footer></body></html>";


// Reemplaza caracteres acentuados por su versión sin tilde
void normalizarTexto(char *str) {
  char *p = str;
  while (*p) {
    unsigned char c = *p;
    if (c == 0xC3) {  // Inicio de secuencia UTF-8 para tildes
      unsigned char next = *(p + 1);
      switch (next) {
        case 0xA1: *p = 'a'; break;  // á
        case 0xA9: *p = 'e'; break;  // é
        case 0xAD: *p = 'i'; break;  // í
        case 0xB3: *p = 'o'; break;  // ó
        case 0xBA: *p = 'u'; break;  // ú
        case 0x81: *p = 'A'; break;  // Á
        case 0x89: *p = 'E'; break;  // É
        case 0x8D: *p = 'I'; break;  // Í
        case 0x93: *p = 'O'; break;  // Ó
        case 0x9A: *p = 'U'; break;  // Ú
        case 0xB1: *p = 'n'; break;  // ñ
        case 0x91: *p = 'N'; break;  // Ñ
        default: *p = ' '; break;    // Caracter desconocido → espacio
      }
      // Saltar el segundo byte UTF-8
      memmove(p + 1, p + 2, strlen(p + 2) + 1);
    }
    p++;
  }
}


// === FUNCIONES DE UTILIDAD ===
// Convierte un carácter hexadecimal a número
uint8_t htoi(char c) {
  c = toupper(c);
  if (c >= '0' && c <= '9') return c - '0';
  if (c >= 'A' && c <= 'F') return c - 'A' + 10;
  return 0;
}

// Parsea la URL recibida para extraer mensaje, dirección y velocidad
void getData(char *req) {
  char *p;
  // Buscar mensaje (MSG=...)
  p = strstr(req, "MSG=");
  if (p) {
    p += 4;
    char *dst = newMessage;
    while (*p && *p != '&') {
      if (*p == '%' && isxdigit(*(p + 1)) && isxdigit(*(p + 2))) {
        p++;
        *dst++ = (htoi(*p++) << 4) | htoi(*p++);
      } else {
        *dst++ = *p++;
      }
    }
    *dst = '\0';
    normalizarTexto(newMessage);
    newMessageAvailable = strlen(newMessage) > 0;
  }
  // Buscar dirección (SD=L o R)
  p = strstr(req, "SD=");
  if (p) scrollRight = (*(p + 3) == 'R');
  // Buscar velocidad (SP=xxx)
  p = strstr(req, "SP=");

  if (p) {
    int val = atoi(p + 3);
    scrollSpeed = 210 - val;  // Invertimos la relación: más barra = más rápido
  }
}

// === VARIABLES DE SCROLL ===
int16_t xPos = MATRIX_COLS;  // Posición horizontal del texto

// === SETUP ===
void setup() {
  Serial.begin(115200);

  // Configurar pines de filas como salida
  for (int i = 0; i < MATRIX_ROWS; i++) {
    pinMode(filas[i], OUTPUT);
    apagarFila(i);
  }
  sr.setAllLow();

  // Configurar display
  display.setFont(&LEMONMILK_Regular10pt7b);  // Fuente
  display.setTextColor(1);                    // Color blanco (LED encendido)
  display.setTextWrap(false);                 // No cortar líneas

  WiFi.mode(WIFI_AP);              // Configura el ESP32 como Access Point
  WiFi.softAP(ssid, password, 1);  // Crea la red "cartel_led"
  Serial.print("IP del AP: ");
  Serial.println(WiFi.softAPIP());  // Normalmente 192.168.4.1

  MDNS.begin("cartelhuergo");

  server.begin();  // Inicia servidor HTTP

  // Cargar mensaje y configuraciones guardadas en Preferences
  prefs.begin("cartel", false);
  String savedMsg = prefs.getString("mensaje", "ELECTRONICA 2025");
  savedMsg.toCharArray(curMessage, BUF_SIZE);
  scrollSpeed = prefs.getUInt("speed", 100);
  scrollRight = prefs.getBool("dir", false);
}

// === LOOP PRINCIPAL ===
void loop() {
  // === ATENDER SERVIDOR WEB ===
  WiFiClient client = server.available();
  static char req[BUF_SIZE];
  static int idx = 0;

  if (client) {

    while (client.connected() && client.available()) {
      char c = client.read();
      if (idx < BUF_SIZE - 1) req[idx++] = c;

      // Fin de la cabecera HTTP
      if (c == '\n' && strstr(req, "\r\n\r\n")) {
        req[idx] = '\0';
        getData(req);  // Extraer parámetros de la petición
        client.print(WebResponse);
        client.print(WebPage);
        client.stop();

        // Si hay nuevo mensaje, reemplazar y guardar
        if (newMessageAvailable) {
          strcpy(curMessage, newMessage);
          newMessageAvailable = false;
          xPos = MATRIX_COLS;

          // Guardar en Preferences
          prefs.putString("mensaje", curMessage);
          prefs.putUInt("speed", scrollSpeed);
          prefs.putBool("dir", scrollRight);
        }
        idx = 0;
        break;
      }
    }
  }

  // === ANIMACIÓN DE SCROLL ===
  static unsigned long lastScroll = 0;
  if (millis() - lastScroll > scrollSpeed) {
    lastScroll = millis();
    xPos += scrollRight ? 1 : -1;  // Mover texto según dirección

    // Obtener ancho del texto
    int16_t x1, y1;
    uint16_t w, h;
    display.getTextBounds(curMessage, 0, 0, &x1, &y1, &w, &h);

    // Resetear posición cuando sale de pantalla
    if (!scrollRight && xPos < -w) xPos = MATRIX_COLS;
    if (scrollRight && xPos > MATRIX_COLS) xPos = -w;
  }

  // Dibujar mensaje en el framebuffer
  display.clear();
  display.setCursor(xPos, 17);  // Posición vertical fija
  display.print(curMessage);

  // Refrescar la matriz LED
  refrescarMatrizCompleta();
}

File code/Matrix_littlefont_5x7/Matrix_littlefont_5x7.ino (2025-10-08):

#include <Arduino.h>
#include <ShiftRegister74HC595.h>  // https://blog.timodenk.com/shift-register-arduino-library/

// === CONFIGURACIÓN DE PINES ===
#define DATA_PIN 23   // DS
#define CLOCK_PIN 18  // SHCP
#define LATCH_PIN 19  // STCP

#define MATRIX_ROWS 18
#define MATRIX_COLS 96

// Instancia de 3 registros 74HC595 (para 24 columnas)
ShiftRegister74HC595<12> sr(DATA_PIN, CLOCK_PIN, LATCH_PIN);

// Pines de filas (controladas por TIP122)
const uint8_t filas[MATRIX_ROWS] = {
  3, 1, 2, 4, 5,
  12, 13, 14, 15, 16,
  17, 21, 22, 25, 26,
  27, 32, 33
};

// ==============================
// Fuente 5x7 (ASCII 32 a 127)
// Cada carácter es 5 columnas (bits verticales), bit 0 abajo
// ==============================
const uint8_t font5x7[][5] = {
  { 0x00, 0x00, 0x00, 0x00, 0x00 },  // 32 ' '
  { 0x00, 0x00, 0x5F, 0x00, 0x00 },  // 33 '!'
  { 0x00, 0x07, 0x00, 0x07, 0x00 },  // 34 '"'
  { 0x14, 0x7F, 0x14, 0x7F, 0x14 },  // 35 '#'
  { 0x24, 0x2A, 0x7F, 0x2A, 0x12 },  // 36 '$'
  { 0x23, 0x13, 0x08, 0x64, 0x62 },  // 37 '%'
  { 0x36, 0x49, 0x55, 0x22, 0x50 },  // 38 '&'
  { 0x00, 0x05, 0x03, 0x00, 0x00 },  // 39 '''
  { 0x00, 0x1C, 0x22, 0x41, 0x00 },  // 40 '('
  { 0x00, 0x41, 0x22, 0x1C, 0x00 },  // 41 ')'
  { 0x14, 0x08, 0x3E, 0x08, 0x14 },  // 42 '*'
  { 0x08, 0x08, 0x3E, 0x08, 0x08 },  // 43 '+'
  { 0x00, 0x50, 0x30, 0x00, 0x00 },  // 44 ','
  { 0x08, 0x08, 0x08, 0x08, 0x08 },  // 45 '-'
  { 0x00, 0x60, 0x60, 0x00, 0x00 },  // 46 '.'
  { 0x20, 0x10, 0x08, 0x04, 0x02 },  // 47 '/'
  { 0x3E, 0x51, 0x49, 0x45, 0x3E },  // 48 '0'
  { 0x00, 0x42, 0x7F, 0x40, 0x00 },  // 49 '1'
  { 0x42, 0x61, 0x51, 0x49, 0x46 },  // 50 '2'
  { 0x21, 0x41, 0x45, 0x4B, 0x31 },  // 51 '3'
  { 0x18, 0x14, 0x12, 0x7F, 0x10 },  // 52 '4'
  { 0x27, 0x45, 0x45, 0x45, 0x39 },  // 53 '5'
  { 0x3C, 0x4A, 0x49, 0x49, 0x30 },  // 54 '6'
  { 0x01, 0x71, 0x09, 0x05, 0x03 },  // 55 '7'
  { 0x36, 0x49, 0x49, 0x49, 0x36 },  // 56 '8'
  { 0x06, 0x49, 0x49, 0x29, 0x1E },  // 57 '9'
  { 0x00, 0x36, 0x36, 0x00, 0x00 },  // 58 ':'
  { 0x00, 0x56, 0x36, 0x00, 0x00 },  // 59 ';'
  { 0x08, 0x14, 0x22, 0x41, 0x00 },  // 60 '<'
  { 0x14, 0x14, 0x14, 0x14, 0x14 },  // 61 '='
  { 0x00, 0x41, 0x22, 0x14, 0x08 },  // 62 '>'
  { 0x02, 0x01, 0x51, 0x09, 0x06 },  // 63 '?'
  { 0x32, 0x49, 0x79, 0x41, 0x3E },  // 64 '@'
  { 0x7E, 0x11, 0x11, 0x11, 0x7E },  // 65 'A'
  { 0x7F, 0x49, 0x49, 0x49, 0x36 },  // 66 'B'
  { 0x3E, 0x41, 0x41, 0x41, 0x22 },  // 67 'C'
  { 0x7F, 0x41, 0x41, 0x22, 0x1C },  // 68 'D'
  { 0x7F, 0x49, 0x49, 0x49, 0x41 },  // 69 'E'
  { 0x7F, 0x09, 0x09, 0x09, 0x01 },  // 70 'F'
  { 0x3E, 0x41, 0x49, 0x49, 0x7A },  // 71 'G'
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
  { 0x00, 0x00, 0x00, 0x00, 0x00 }   // 127 (DEL) - vacío
};


// Buffer de pantalla
uint8_t buffer[MATRIX_ROWS][MATRIX_COLS] = { 0 };

// ==============================
// Funciones de control de filas
// ==============================
void prenderFila(uint8_t fila) {
  digitalWrite(filas[fila], HIGH);
}

void apagarFila(uint8_t fila) {
  digitalWrite(filas[fila], LOW);
}

// ==============================
// Dibuja un carácter en el buffer
// ==============================
void dibujarChar(char c, int x, int y) {
  if (c < 32 || c > 126) c = 32;  // espacio si no existe
  const uint8_t *bitmap = font5x7[c - 32];
  for (int col = 0; col < 5; col++) {
    uint8_t colBits = bitmap[col];
    for (int row = 0; row < 7; row++) {
      bool pixel = colBits & (1 << row);
      int dx = x + col;
      int dy = y + row;
      if (dx >= 0 && dx < MATRIX_COLS && dy >= 0 && dy < MATRIX_ROWS) {
        buffer[dy][dx] = pixel;
      }
    }
  }
}

// ==============================
// Desplaza el buffer a la izquierda
// ==============================
void scrollIzquierda() {
  for (int row = 0; row < MATRIX_ROWS; row++) {
    for (int col = 0; col < MATRIX_COLS - 1; col++) {
      buffer[row][col] = buffer[row][col + 1];
    }
    buffer[row][MATRIX_COLS - 1] = 0;
  }
}

// ==============================
// Refresca la matriz (multiplexado)
// ==============================
void refrescarMatriz() {
  for (int fila = 0; fila < MATRIX_ROWS; fila++) {
    apagarFila(fila); // Apagamos fila antes de cambiar columnas
  }

  for (int fila = 0; fila < MATRIX_ROWS; fila++) {
    // Preparamos los datos de las columnas
    sr.setAllLow();
    for (int col = 0; col < MATRIX_COLS; col++) {
      sr.set(col, buffer[fila][col] ? HIGH : LOW);
    }
    prenderFila(fila);
    delayMicroseconds(50); // Mucho más rápido para que sea invisible
    apagarFila(fila);
  }
}


// ==============================
// Configuración
// ==============================
const char mensaje[] = "BIENVENIDOS EXPO HUERGO 2025 ";

void setup() {
  for (int i = 0; i < MATRIX_ROWS; i++) {
    pinMode(filas[i], OUTPUT);
    apagarFila(i);
  }
  sr.setAllLow();

  // Dibuja la primera letra justo al inicio, centrada verticalmente
  dibujarChar(mensaje[0], MATRIX_COLS - 5, 5);
}

// ==============================
// Programa principal
// ==============================
int charIndex = 0;
int colCount = 0;

void loop() {

  // Refresco continuo
  refrescarMatriz();

  static unsigned long lastScroll = 0;
  if (millis() - lastScroll > 100) {  // velocidad scroll
    lastScroll = millis();
    scrollIzquierda();
    colCount++;
    if (colCount >= 6) {  // 5 columnas + 1 espacio
      colCount = 0;
      charIndex++;
      if (charIndex >= strlen(mensaje)) charIndex = 0;
      dibujarChar(mensaje[charIndex], MATRIX_COLS - 5, 5);  // y=5 para centrar vertical
    }
  }
}

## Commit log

2025-08-06 agrego en code un archivo testing simplificado
    [74hc595.dsn, 74hc595.kicad_pcb, 74hc595.kicad_sch]
2025-08-07 attempt to turn on just one led
2025-08-08 update assets PCB
    [ESP32+TIPS (1).dsn, ESP32+TIPS (1).kicad_pcb, ESP32+TIPS (1).kicad_sch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]
2025-08-08 update pcb
    [ESP32+TIPS (1).kicad_pcb]
2025-08-10 Update para prender unico led
2025-08-12 update after matrix working
    [ESP32+TIPS (1).dsn, ESP32+TIPS (1).kicad_pcb, ESP32+TIPS (1).kicad_sch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]
2025-09-05 update refrezcarMatrizcompleta para mas registros
2025-10-08 finding the final
    [cartelmatriz.kicad_sch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]
